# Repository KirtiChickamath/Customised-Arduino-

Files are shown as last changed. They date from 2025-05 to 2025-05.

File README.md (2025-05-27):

# Customised-Arduino-
Custom Arduino-compatible PCB project using ATmega328P which includes motor control, 7-segment display, and power supply design
It was developed as part of a course I took from Internshala.

## Project Details

**Project Name:** Customised Arduino

**Software Used:** Eagle 

**Tutorial Reference:**  
This project was developed as part of a course from [Internshala](https://internshala.com/).

## Features

- Powered by a 7805 voltage regulator converting 12V to 5V  
- Controls two small DC motors using the L293D motor driver IC  
- Motor speed can be controlled both via computer commands and manually using a potentiometer on the board  
- Seven-segment display driven by the CD4511BE driver IC, showing numbers 0-9  
- One RGB LED controlled by both the microcontroller and a simple switch on the board

## Project Files

- `Schematic` -- Circuit diagrams  
- `PCB Layout` -- PCB design layout  
- `CAM Outputs` -- Manufacturing files for PCB fabrication  
- `BOM` -- Bill of Materials listing all components   
- `Images` -- Board photos and design previews  
- `Libraries` -- Libraries were provided by mentor

## Images

### Schematic

Schematic

### PCB Layout

Layout

## Credits

This project was developed as part of a course from [Internshala](https://internshala.com/).  

All credit goes to the course instructors and materials that guided this work.

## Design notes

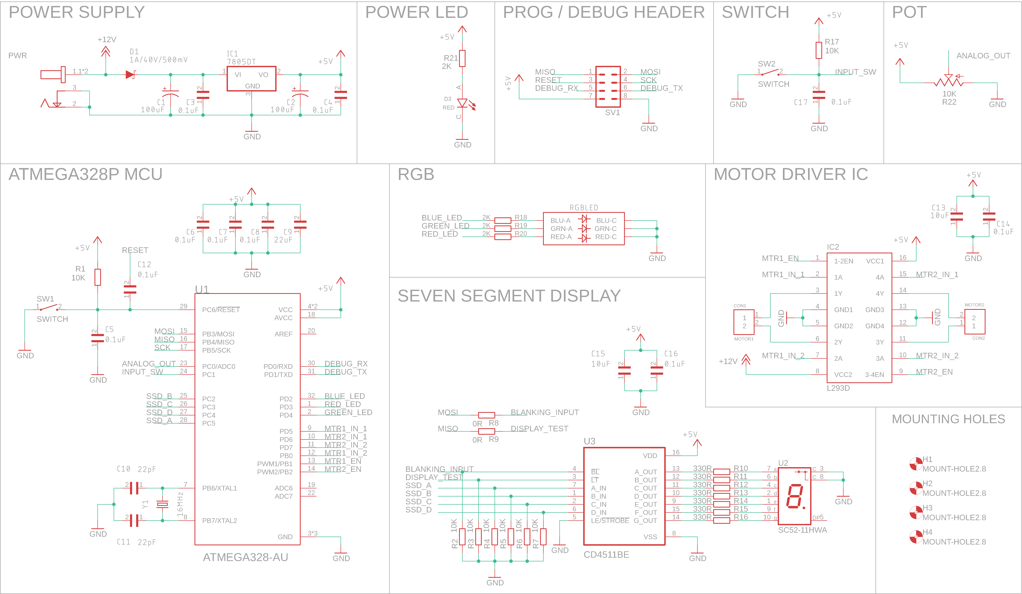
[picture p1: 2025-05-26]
Images/Schematic.png

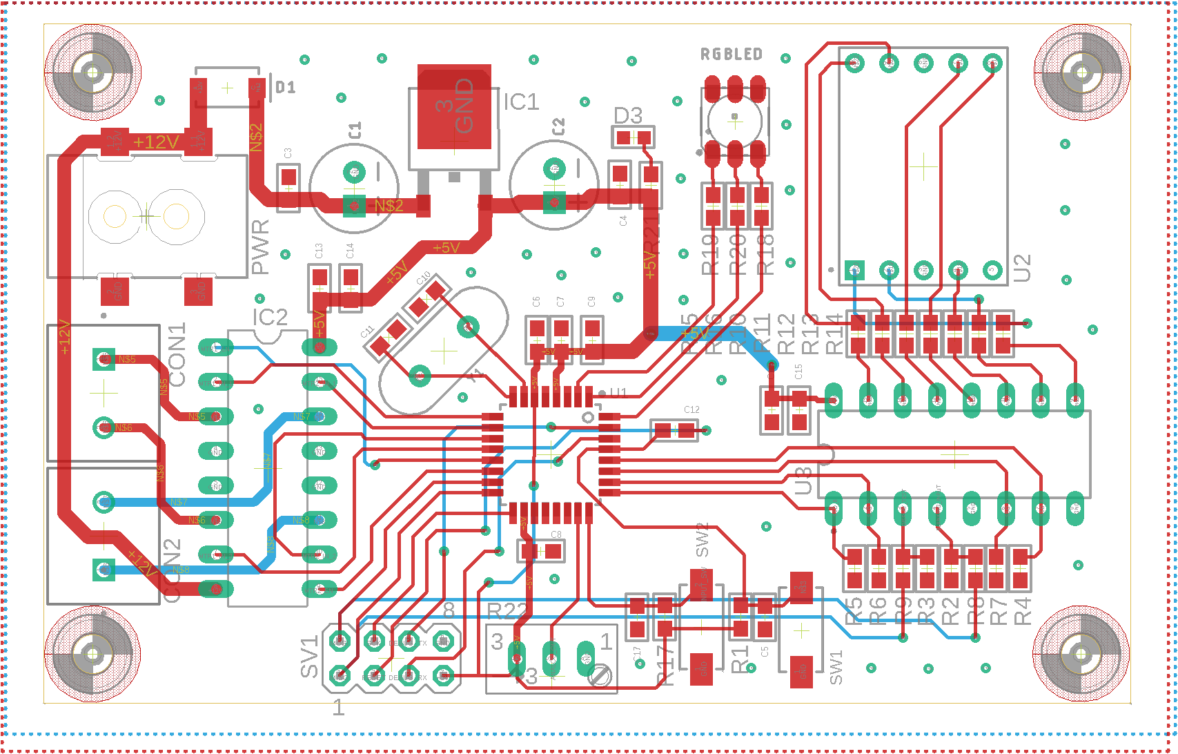
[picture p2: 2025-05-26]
Images/Layout.png

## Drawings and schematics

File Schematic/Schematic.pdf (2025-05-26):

## RED 2K

POWER SUPPLY | PROG / DEBUG HEADER

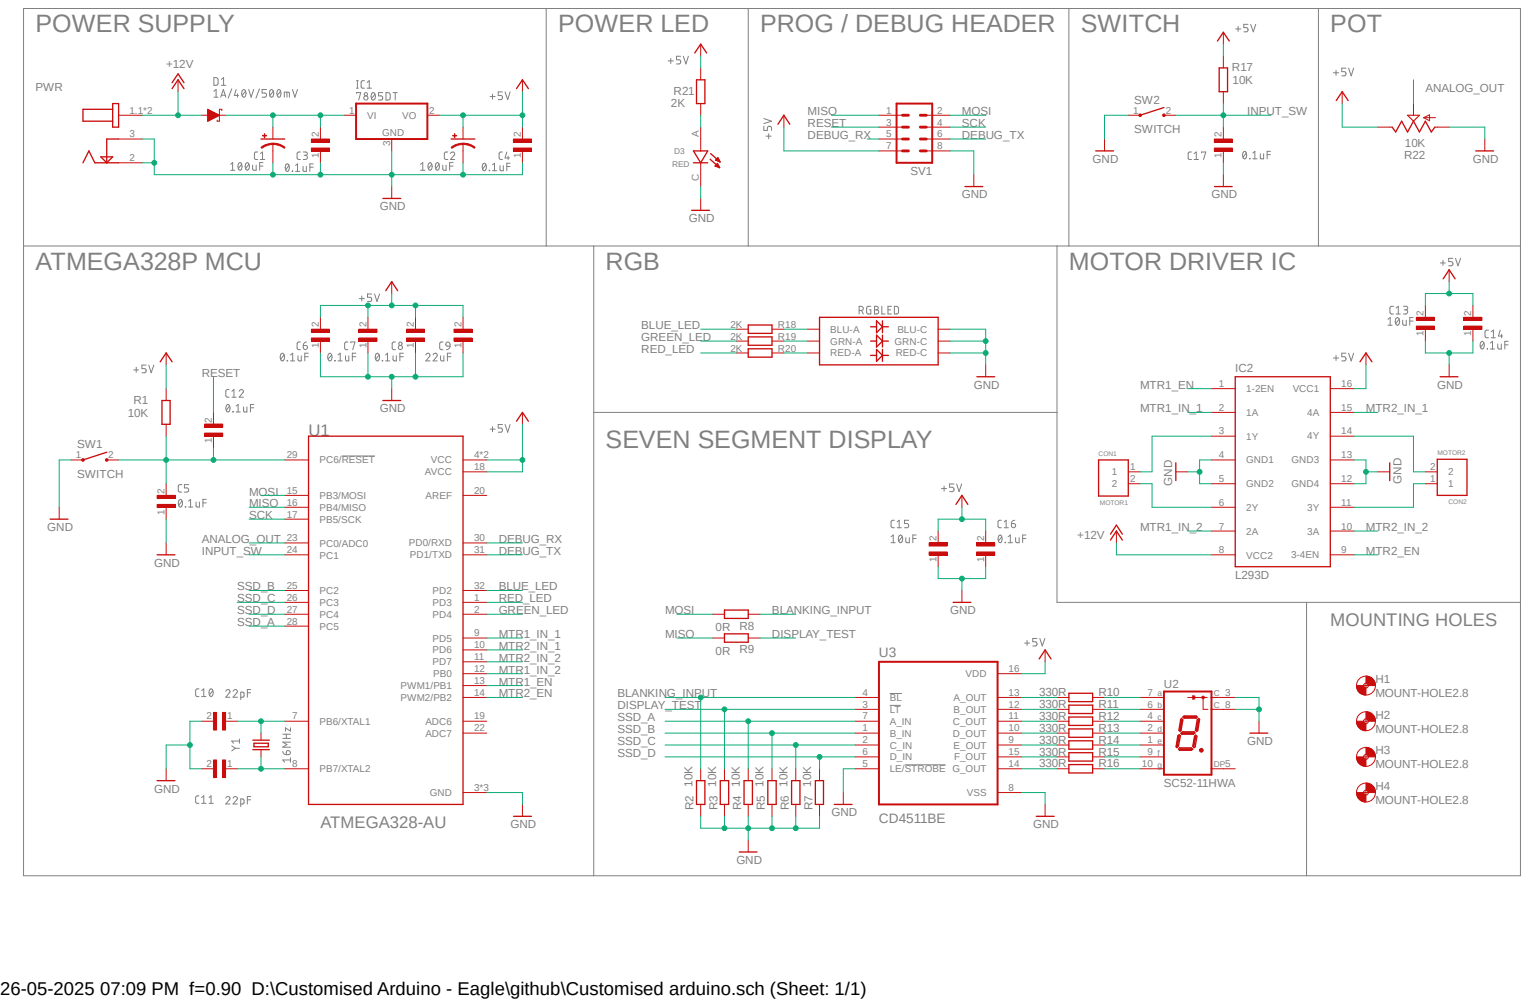
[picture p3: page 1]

26-05-2025 07:09 PM f=0.90 D:\Customised Arduino - Eagle\github\Customised arduino.sch (Sheet: 1/1)

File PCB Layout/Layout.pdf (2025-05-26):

## D3 PWR

IC1

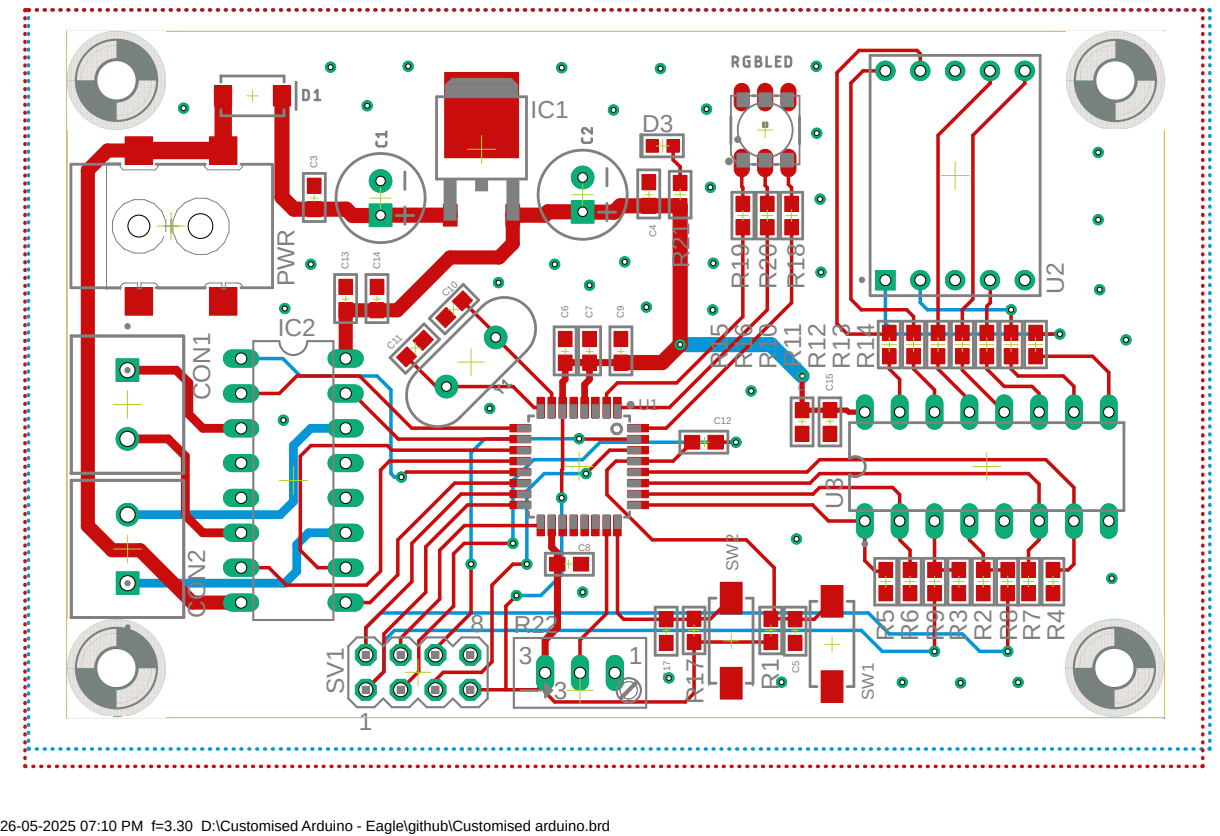
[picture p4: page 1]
C12 C¹³; C¹⁴; C¹⁶; C¹⁵ C¹⁷ C³; C⁹ CON¹; IC2 CON²; R¹ R¹⁵ R¹⁶ R¹⁰ R¹¹ R¹² R¹³ R¹⁴ R¹⁷ R¹⁹; R¹⁸; R² R²⁰R²¹; R⁸ R⁷ R⁴ SV¹; SW¹ SW²

26-05-2025 07:10 PM f=3.30 D:\Customised Arduino - Eagle\github\Customised arduino.brd

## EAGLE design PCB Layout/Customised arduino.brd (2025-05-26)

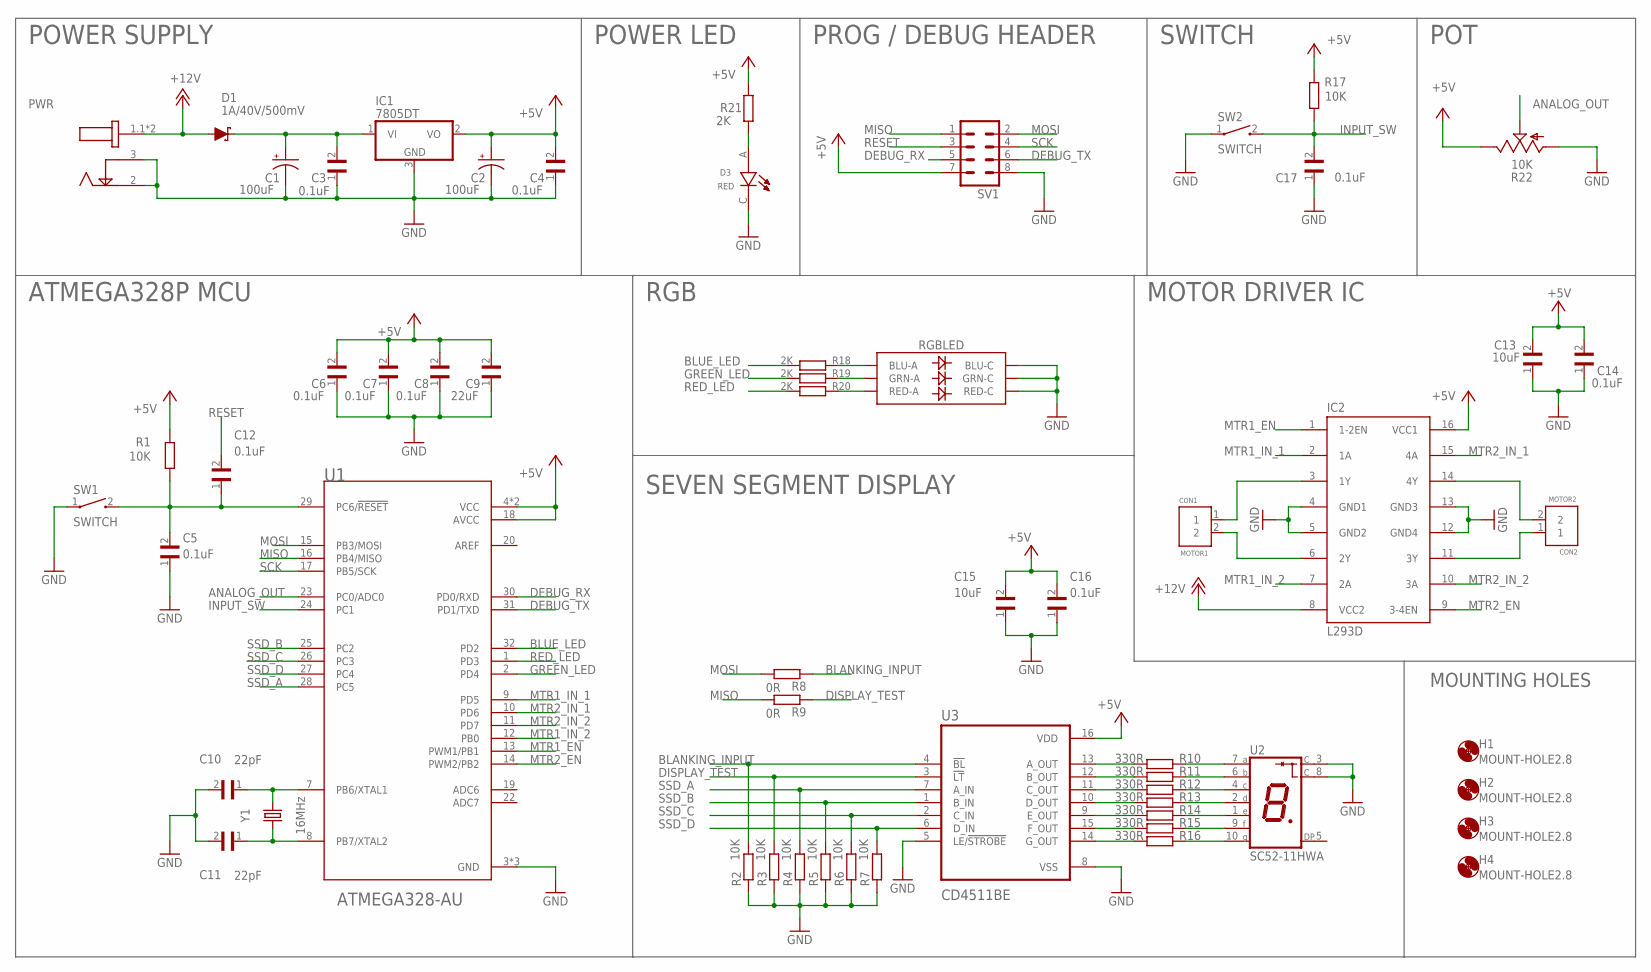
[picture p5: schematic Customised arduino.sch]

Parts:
C1, C2: 100uF; CPOL-RADIAL-2.5MM-6.5MM
C3, C4, C5, C6, C7, C8, C12, C14, C16, C17: 0.1uF; C0603
C9: 22uF; C0603
C10, C11: 22pF; C0603
C13, C15: 10uF; C0603
CON1: MOTOR1; CONN_282836-2
CON2: MOTOR2; CONN_282836-2
D1: 1A/40V/500mV; SMA-DIODE
D3: RED; LEDC1608X65N
H1, H2, H3, H4: MOUNT-HOLE2.8; 2,8
IC1: 7805DT; TO252
IC2: L293D; DIL16
PWR: DCJ200-05-A-XX-X_REVA; GCT_DCJ200-05-A-XX-X_REVA
R1, R2, R3, R4, R5, R6, R7, R17: 10K; R0603
R8, R9: 0R; R0603
R10, R11, R12, R13, R14, R15, R16: 330R; R0603
R18, R19, R20, R21: 2K; R0603
R22: 10K; S64W
RGBLED: LED-RGBNO_IC; LED-TRICOLOR-5050
SV1: MA04-2
SW1, SW2: SWITCH; SW_1437566-3
U1: ATMEGA328-AU; QFP80P900X900X120-32N
U2: SC52-11HWA; LED_SC52-11HWA
U3: CD4511BE; DIP794W45P254L1969H508Q16
Y1: 16MHz; HC49US

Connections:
+5V: C2.1 (+), C4.2, C6.2, C7.2, C8.2, C9.2, C13.2, C14.2, C15.2, C16.2, IC1.2 (VO), IC2.16 (VCC1), R1.2, R17.2, R21.2, R22.E, SV1.7, U1.4 (VCC), U1.6 (VCC), U1.18 (AVCC), U3.16 (VDD)
+12V: D1.A, IC2.8 (VCC2), PWR.1.1 (1), PWR.1.2 (1)
ANALOG_OUT: R22.S, U1.23 (PC0/ADC0)
BLANKING_INPUT: R2.2, R8.1, U3.4 (!BL)
BLUE_LED: R18.2, U1.32 (PD2)
DEBUG_RX: SV1.5, U1.30 (PD0/RXD)
DEBUG_TX: SV1.6, U1.31 (PD1/TXD)
DISPLAY_TEST: R3.2, R9.1, U3.3 (!LT)
GND: C1.2 (-), C2.2 (-), C3.1, C4.1, C5.1, C6.1, C7.1, C8.1, C9.1, C10.2, C11.2, C13.1, C14.1, C15.1, C16.1, C17.1, D3.C, IC1.3 (GND), IC2.4 (GND1), IC2.5 (GND2), IC2.12 (GND4), IC2.13 (GND3), PWR.2, PWR.3, R2.1, R3.1, R4.1, R5.1, R6.1, R7.1, R22.A, RGBLED.4 (BLU-C), RGBLED.5 (RED-C), RGBLED.6 (GRN-C), SV1.8, SW1.1, SW2.1, U1.3 (GND), U1.5 (GND), U1.21 (GND), U2.3 (C), U2.8 (C), U3.5 (LE/!STROBE), U3.8 (VSS)
GREEN_LED: R19.2, U1.2 (PD4)
INPUT_SW: C17.2, R17.1, SW2.2, U1.24 (PC1)
MISO: R9.2, SV1.1, U1.16 (PB4/MISO)
MOSI: R8.2, SV1.2, U1.15 (PB3/MOSI)
MTR1_EN: IC2.1 (1-2EN), U1.13 (PWM1/PB1)
MTR1_IN_1: IC2.2 (1A), U1.9 (PD5)
MTR1_IN_2: IC2.7 (2A), U1.12 (PB0)
MTR2_EN: IC2.9 (3-4EN), U1.14 (PWM2/PB2)
MTR2_IN_1: IC2.15 (4A), U1.10 (PD6)
MTR2_IN_2: IC2.10 (3A), U1.11 (PD7)
unnamed: C10.1, U1.7 (PB6/XTAL1), Y1.2
unnamed: C1.1 (+), C3.2, D1.C, IC1.1 (VI)
unnamed: C5.2, C12.1, R1.1, SW1.2, U1.29 (PC6/!RESET)
unnamed: C11.1, U1.8 (PB7/XTAL2), Y1.1
unnamed: CON1.1, IC2.3 (1Y)
unnamed: CON1.2, IC2.6 (2Y)
unnamed: CON2.2, IC2.14 (4Y)
unnamed: CON2.1, IC2.11 (3Y)
unnamed: R10.2, U3.13 (A_OUT)
unnamed: R11.2, U3.12 (B_OUT)
unnamed: R12.2, U3.11 (C_OUT)
unnamed: R13.2, U3.10 (D_OUT)
unnamed: R14.2, U3.9 (E_OUT)
unnamed: R15.2, U3.15 (F_OUT)
unnamed: R16.2, U3.14 (G_OUT)
unnamed: R10.1, U2.7 (A)
unnamed: R11.1, U2.6 (B)
unnamed: R12.1, U2.4 (C)
unnamed: R13.1, U2.2 (D)
unnamed: R14.1, U2.1 (E)
unnamed: R15.1, U2.9 (F)
unnamed: R16.1, U2.10 (G)
unnamed: R18.1, RGBLED.3 (BLU-A)
unnamed: R19.1, RGBLED.1 (GRN-A)
unnamed: R20.1, RGBLED.2 (RED-A)
unnamed: D3.A, R21.1
RED_LED: R20.2, U1.1 (PD3)
RESET: C12.2, SV1.3
SCK: SV1.4, U1.17 (PB5/SCK)
SSD_A: R4.2, U1.28 (PC5), U3.7 (A_IN)
SSD_B: R5.2, U1.25 (PC2), U3.1 (B_IN)
SSD_C: R6.2, U1.26 (PC3), U3.2 (C_IN)
SSD_D: R7.2, U1.27 (PC4), U3.6 (D_IN)

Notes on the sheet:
POWER SUPPLY
PROG / DEBUG HEADER
ATMEGA328P MCU
MOTOR DRIVER IC
SEVEN SEGMENT DISPLAY
SWITCH
RGB
POWER LED
MOUNTING HOLES
POT

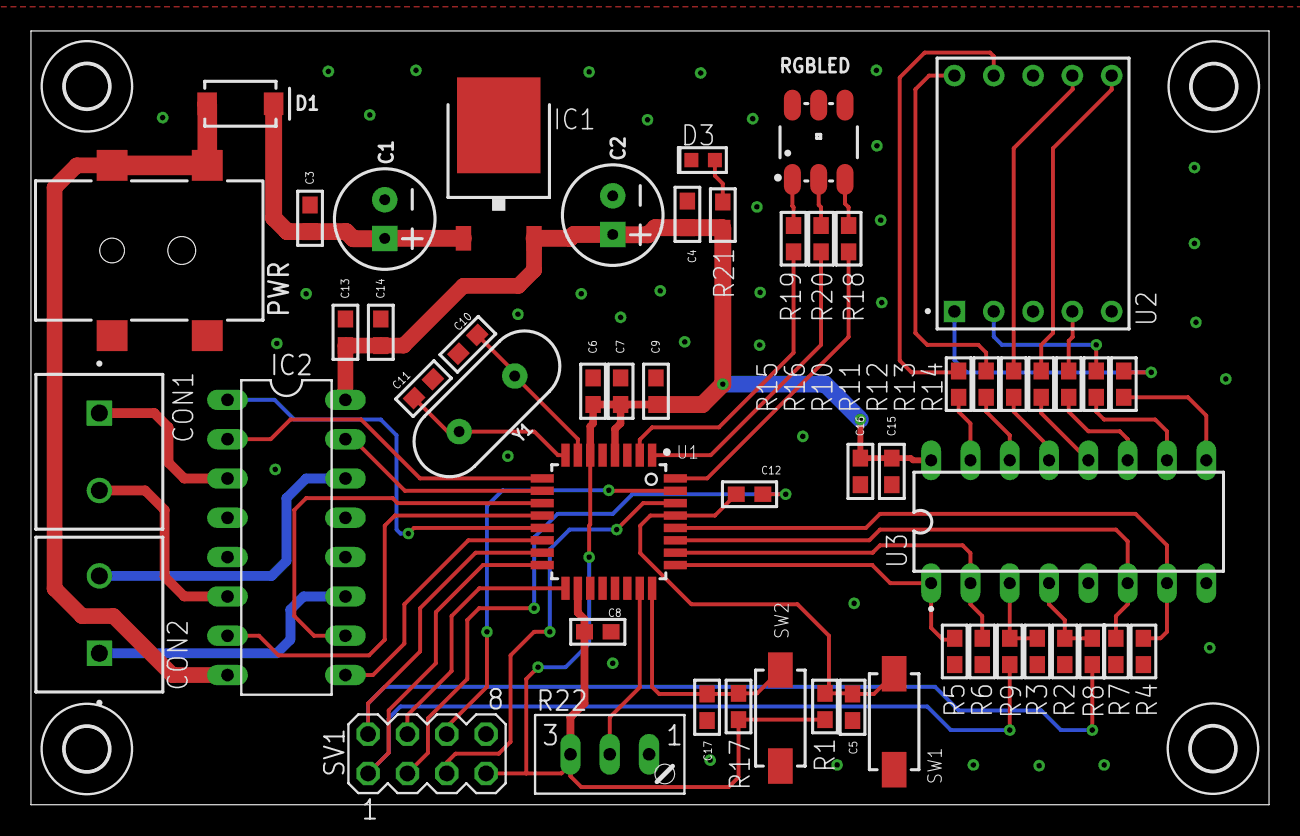
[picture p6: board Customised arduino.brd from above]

Board: 2 copper layers, 80.0 x 50.0 mm, 58 parts (0 on the bottom side), 52 nets.
